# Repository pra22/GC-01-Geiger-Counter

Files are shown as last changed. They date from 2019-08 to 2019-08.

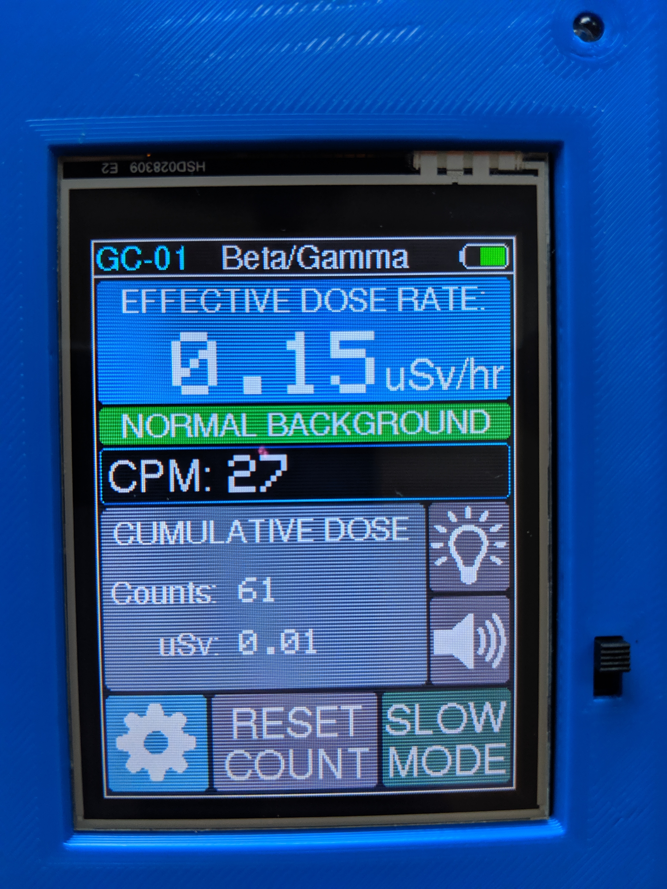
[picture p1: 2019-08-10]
UI Homepage.jpg

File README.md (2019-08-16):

# GC-01-Geiger-Counter
Code and schematics for the GC-01 Geiger counter  

The main program is in src/main.cpp  
Gerbers.zip is the zip file that contains the gerber files for PCB manufacturing. The .zip can be directly uploaded to a PCB manufacturer
like JLCPCB.   
Please refer to the instructable in this link for more details about the porject: https://www.instructables.com/id/DIY-Geiger-Counter-With-an-ESP8266-and-a-Touchscre/

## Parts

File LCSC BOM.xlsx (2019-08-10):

LCSC Part Number | Manufacture Part Number | Manufacturer | Customer NO. | Package | Description | RoHS | Order Qty. | Min\Mult Order Qty. | Unit Price | Order Price
C96061 | PS1720P02 | TDK |  | Plugin | Buzzers Piezo NO 2000Hz 3V Φ17mm Plugin RoHS | Yes | 1 | 1\1 | $0.1697 | $0.17
C99758 | 333-2SURD/S530-A3-L | Everlight Elec |  | Through Hole | Light Emitting Diodes (LED) Red 624nm 200mcd@20mA Top View Through Hole RoHS | Yes | 10 | 10\10 | $0.0355 | $0.36
C118538 | 2N3904 | Semtech |  | TO-92(TO-92-3) | Transistors (NPN/PNP) NPN 200mA 40V TO-92(TO-92-3) RoHS | Yes | 50 | 50\50 | $0.0111 | $0.56
C119313 | - | Chian Chia Elec |  | Axial | Metal Film Resistor (TH) 330Ohms ±1% 1/4W Axial RoHS | Yes | 50 | 50\50 | $0.0053 | $0.27
C119354 | - | Chian Chia Elec |  | Axial | Metal Film Resistor (TH) 22KOhms ±1% 1/4W Axial RoHS | Yes | 50 | 50\50 | $0.0052 | $0.26
C136528 | - | Chian Chia Elec |  | Axial | Metal Film Resistor (TH) 6.2MOhms ±1% 1/4W Axial RoHS | Yes | 50 | 50\50 | $0.0095 | $0.48
C136529 | - | Chian Chia Elec |  | Axial | Metal Film Resistor (TH) 10MOhms ±1% 1/4W Axial RoHS | Yes | 50 | 50\50 | $0.0092 | $0.46
C136718 | SS-12F44-G5 | Korean Hroparts Elec |  | Plugin | Toggle Switches Plugin RoHS | Yes | 5 | 5\5 | $0.0766 | $0.39
C176514 | MFR-25JT-52-3M | YAGEO |  | Axial | Metal Film Resistor (TH) 3MOhms ±5% 1/4W Axial RoHS | Yes | 20 | 20\20 | $0.0168 | $0.34
C182321 | LS-601 | Shenzhen lanson Elec |  | 6.35*32 | Fuse Holders 6.35*32 RoHS | Yes | 10 | 10\10 | $0.0364 | $0.37
C330752 | TJ-L3FYTGHTFCSFLC2R-A5 | TOGIALED |  | Through Hole | Light Emitting Diodes (LED) Red 620~630nm 200~500mcd@20mA Through Hole RoHS | Yes | 20 | 20\20 | $0.0197 | $0.4
C366787 | L06B1B221KQ0T0S0N0 | Songtian Elec |  | Through Hole,P=5.0mm | Ceramic Disc Capacitors 220pF ±10% 500V Through Hole,P=5.0mm RoHS | Yes | 50 | 50\50 | $0.0145 | $0.73
C385438 | RN1/2WS1.8MΩFT/BA1 | TyoHM |  | Axial,2.4x6.5mm | Metal Film Resistor (TH) 1.8MOhms ±1% 1/2W Axial,2.4x6.5mm RoHS | Yes | 50 | 50\50 | $0.0093 | $0.47

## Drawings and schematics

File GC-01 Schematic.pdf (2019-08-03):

## VCC

## VCC

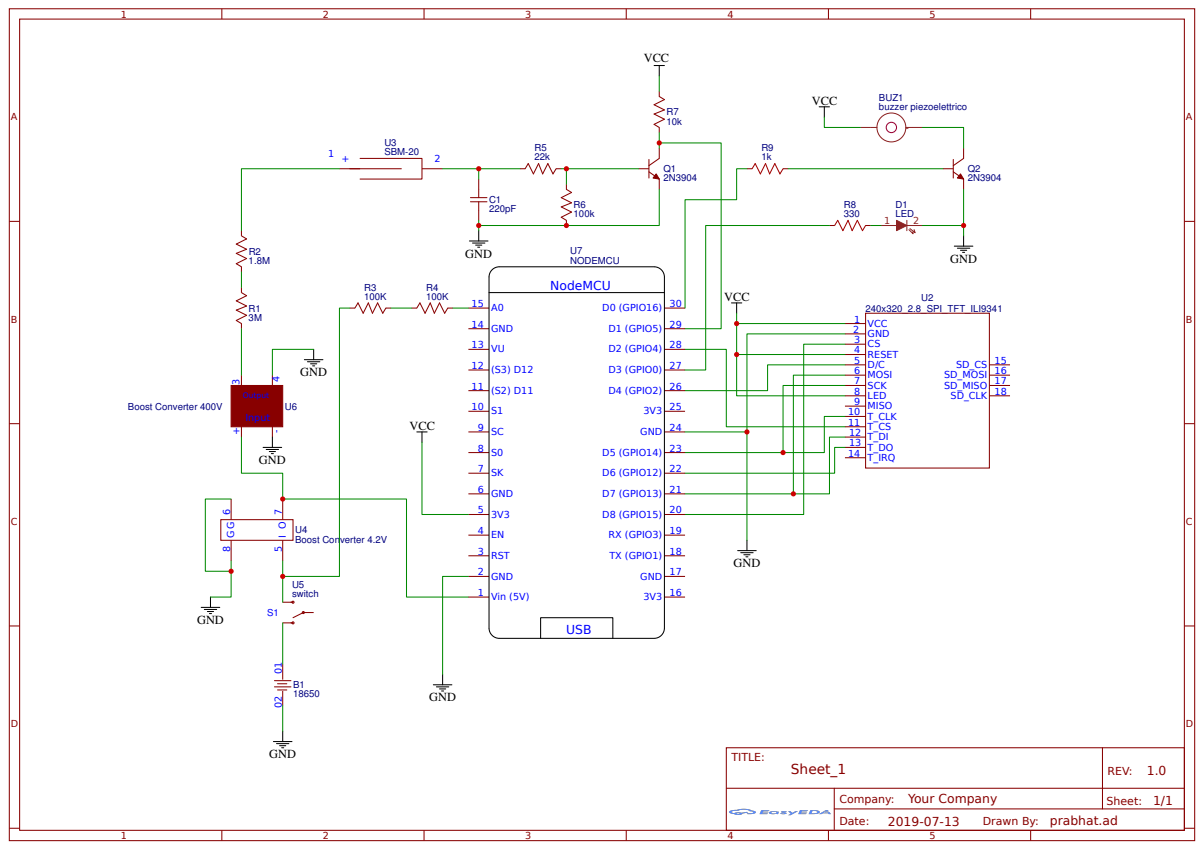
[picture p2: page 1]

Drawn By: prabhat.ad

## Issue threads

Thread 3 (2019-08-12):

BOM Does Not Match Schematic

tonyc770, 2019-08-12:
I noticed that the BOM parts don't all match the schematic. Can you verify?

Thanks!

pra22, 2019-08-12:
Oh that's right I forgot about that. I have edited the Instructables post to include a list of what's needed.

Closed 2019-08-12.

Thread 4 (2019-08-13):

BOM and Schematic Differ

tonyc770, 2019-08-13:
In the BOM it lists a 10M, and 6.2M resistors, but they are not shown in the schematic.
The schematic shows 3, 100K and a 1K resistors, but not in BOM.

pra22, 2019-08-13:
The 10M and 6.2M resistors are for testing, and are not needed for the project. The new list shown in the Instructables is correct.

Closed 2019-08-24.

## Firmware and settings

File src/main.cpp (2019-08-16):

/*  SBM-20 based Geiger Counter
    Author: Prabhat    Email: pra22@pitt.edu
    Sketch for ESP8266 that counts clicks from the Geiger tube, calculates the counts per minute, and displays information 
    on a TFT touchscreen.
    Attribution-NonCommercial-ShareAlike 4.0 International (CC BY-NC-SA 4.0)
*/
#include <Arduino.h>
#include <ESP8266WiFi.h>
#include <EEPROM.h>
#include "SPI.h"
#include "Adafruit_GFX.h"
#include <Fonts/FreeSans9pt7b.h>
#include <Fonts/FreeSans12pt7b.h>
#include "Adafruit_ILI9341.h"
#include <XPT2046_Touchscreen.h>

#define CS_PIN D2
XPT2046_Touchscreen ts(CS_PIN);

#define TS_MINX 250
#define TS_MINY 200 // calibration points for touchscreen
#define TS_MAXX 3800
#define TS_MAXY 3750

#define TFT_DC D4
#define TFT_CS D8

#define BLACK 0x0000
#define BLUE 0x001F
#define RED 0xF800
#define GREEN 0x07E0
#define CYAN 0x07FF
#define MAGENTA 0xF81F
#define YELLOW 0xFFE0
#define WHITE 0xFFFF
#define DOSEBACKGROUND 0x0455

Adafruit_ILI9341 tft = Adafruit_ILI9341(TFT_CS, TFT_DC);

const int interruptPin = 5;

long count[61];
long fastCount[4]; // arrays to store running counts
int i = 0;         // array elements
int j = 0;

int page = 0;

long currentMillis;
long previousMillis;
unsigned long currentMicros;
unsigned long previousMicros;

long averageCount;
unsigned long currentCount;  // incremented by interrupt
unsigned long previousCount; // to activate buzzer and LED
unsigned long cumulativeCount;
float doseRate;
float totalDose;
char dose[5];
float doseAdjusted;

int doseLevel;               // determines home screen warning signs
int previousDoseLevel;

bool ledSwitch = 1;
bool buzzerSwitch = 1;
bool wasTouched;
bool integrationMode = 0; // 0 = slow, 1 = fast

bool doseUnits = 0; // 0 = Sievert, 1 = Rem
int alarmThreshold = 5;
int conversionFactor = 175;

int x, y; // touch points

int batteryInput;
int batteryPercent;
int batteryMapped = 212;       // pixel location of battery icon

const int saveUnits = 0;
const int saveAlertThreshold = 1; // Addresses for storing settings data in the EEPROM
const int saveCalibration = 2;

void ICACHE_RAM_ATTR isr();

const unsigned char settingsBitmap[] PROGMEM = {
    0x00, 0x00, 0x00, 0x00, 0x00, 0x00, 0x00, 0x00, 0x00, 0x00, 0x00, 0x00, 0x00, 0x00, 0x00, 0x00,
    0x00, 0x00, 0x00, 0x00, 0x00, 0x00, 0x00, 0x00, 0x00, 0x00, 0x00, 0x00, 0x00, 0x00, 0x00, 0x00,
    0x00, 0x00, 0x00, 0x00, 0x00, 0x00, 0x00, 0x00, 0x00, 0x00, 0x00, 0x00, 0x00, 0x00, 0x00, 0x00,
    0x00, 0x00, 0x00, 0x00, 0x00, 0x00, 0x00, 0x00, 0x00, 0x00, 0x00, 0x1f, 0x80, 0x00, 0x00, 0x00,
    0x00, 0x00, 0x00, 0x3f, 0xc0, 0x00, 0x00, 0x00, 0x00, 0x00, 0x00, 0x3f, 0xc0, 0x00, 0x00, 0x00,
    0x00, 0x00, 0x00, 0x3f, 0xc0, 0x00, 0x00, 0x00, 0x00, 0x00, 0x00, 0x7f, 0xe0, 0x00, 0x00, 0x00,
    0x00, 0x01, 0xc0, 0x7f, 0xe0, 0x38, 0x00, 0x00, 0x00, 0x03, 0xf0, 0x7f, 0xe0, 0xfc, 0x00, 0x00,
    0x00, 0x07, 0xf9, 0xff, 0xf9, 0xfe, 0x00, 0x00, 0x00, 0x0f, 0xff, 0xff, 0xff, 0xff, 0x00, 0x00,
    0x00, 0x0f, 0xff, 0xff, 0xff, 0xff, 0x00, 0x00, 0x00, 0x0f, 0xff, 0xff, 0xff, 0xff, 0x00, 0x00,
    0x00, 0x07, 0xff, 0xff, 0xff, 0xfe, 0x00, 0x00, 0x00, 0x07, 0xff, 0xff, 0xff, 0xfe, 0x00, 0x00,
    0x00, 0x03, 0xff, 0xff, 0xff, 0xfc, 0x00, 0x00, 0x00, 0x01, 0xff, 0xff, 0xff, 0xf8, 0x00, 0x00,
    0x00, 0x01, 0xff, 0xff, 0xff, 0xf8, 0x00, 0x00, 0x00, 0x03, 0xff, 0xf0, 0x7f, 0xfc, 0x00, 0x00,
    0x00, 0x03, 0xff, 0xc0, 0x3f, 0xfc, 0x00, 0x00, 0x00, 0x1f, 0xff, 0x80, 0x1f, 0xff, 0x80, 0x00,
    0x00, 0xff, 0xff, 0x00, 0x0f, 0xff, 0xf0, 0x00, 0x01, 0xff, 0xff, 0x00, 0x07, 0xff, 0xf8, 0x00,
    0x01, 0xff, 0xfe, 0x00, 0x07, 0xff, 0xf8, 0x00, 0x01, 0xff, 0xfe, 0x00, 0x07, 0xff, 0xf8, 0x00,
    0x01, 0xff, 0xfe, 0x00, 0x07, 0xff, 0xf8, 0x00, 0x01, 0xff, 0xfe, 0x00, 0x07, 0xff, 0xf8, 0x00,
    0x01, 0xff, 0xfe, 0x00, 0x07, 0xff, 0xf8, 0x00, 0x00, 0xff, 0xff, 0x00, 0x0f, 0xff, 0xf0, 0x00,
    0x00, 0x1f, 0xff, 0x80, 0x1f, 0xff, 0x80, 0x00, 0x00, 0x03, 0xff, 0xc0, 0x3f, 0xfc, 0x00, 0x00,
    0x00, 0x03, 0xff, 0xe0, 0x7f, 0xfc, 0x00, 0x00, 0x00, 0x01, 0xff, 0xff, 0xff, 0xf8, 0x00, 0x00,
    0x00, 0x01, 0xff, 0xff, 0xff, 0xf8, 0x00, 0x00, 0x00, 0x03, 0xff, 0xff, 0xff, 0xfc, 0x00, 0x00,
    0x00, 0x07, 0xff, 0xff, 0xff, 0xfe, 0x00, 0x00, 0x00, 0x07, 0xff, 0xff, 0xff, 0xfe, 0x00, 0x00,
    0x00, 0x0f, 0xff, 0xff, 0xff, 0xff, 0x00, 0x00, 0x00, 0x0f, 0xff, 0xff, 0xff, 0xff, 0x00, 0x00,
    0x00, 0x0f, 0xff, 0xff, 0xff, 0xff, 0x00, 0x00, 0x00, 0x07, 0xf9, 0xff, 0xf9, 0xfe, 0x00, 0x00,
    0x00, 0x03, 0xf0, 0x7f, 0xe0, 0xfc, 0x00, 0x00, 0x00, 0x01, 0xc0, 0x7f, 0xe0, 0x38, 0x00, 0x00,
    0x00, 0x00, 0x00, 0x7f, 0xe0, 0x00, 0x00, 0x00, 0x00, 0x00, 0x00, 0x3f, 0xc0, 0x00, 0x00, 0x00,
    0x00, 0x00, 0x00, 0x3f, 0xc0, 0x00, 0x00, 0x00, 0x00, 0x00, 0x00, 0x3f, 0xc0, 0x00, 0x00, 0x00,
    0x00, 0x00, 0x00, 0x1f, 0x80, 0x00, 0x00, 0x00, 0x00, 0x00, 0x00, 0x00, 0x00, 0x00, 0x00, 0x00,
    0x00, 0x00, 0x00, 0x00, 0x00, 0x00, 0x00, 0x00, 0x00, 0x00, 0x00, 0x00, 0x00, 0x00, 0x00, 0x00,
    0x00, 0x00, 0x00, 0x00, 0x00, 0x00, 0x00, 0x00, 0x00, 0x00, 0x00, 0x00, 0x00, 0x00, 0x00, 0x00,
    0x00, 0x00, 0x00, 0x00, 0x00, 0x00, 0x00, 0x00, 0x00, 0x00, 0x00, 0x00, 0x00, 0x00, 0x00, 0x00};

const unsigned char buzzerOnBitmap[] PROGMEM = {
    0x00, 0x00, 0x00, 0x00, 0x00, 0x00, 0x00, 0x00, 0x00, 0x00, 0x00, 0x00, 0x00, 0x00, 0x00, 0x00,
    0x00, 0x00, 0x00, 0x00, 0x00, 0x00, 0x00, 0x00, 0x00, 0x00, 0x00, 0x00, 0x00, 0x00, 0x00, 0x00,
    0x00, 0x00, 0x00, 0x00, 0x00, 0x00, 0x00, 0x00, 0x00, 0x00, 0x00, 0x00, 0x03, 0x80, 0x0c, 0x00,
    0x00, 0x00, 0x07, 0x80, 0x0e, 0x00, 0x00, 0x00, 0x0f, 0x80, 0x0f, 0x00, 0x00, 0x00, 0x1f, 0x80,
    0x07, 0x00, 0x00, 0x00, 0x3f, 0x80, 0xc7, 0x80, 0x00, 0x00, 0xff, 0x80, 0xe3, 0x80, 0x00, 0x01,
    0xff, 0x80, 0xf3, 0xc0, 0x00, 0x03, 0xff, 0x80, 0x71, 0xc0, 0x00, 0x07, 0xff, 0x8c, 0x79, 0xc0,
    0x3f, 0xff, 0xff, 0x9e, 0x38, 0xe0, 0x3f, 0xff, 0xff, 0x8e, 0x38, 0xe0, 0x3f, 0xff, 0xff, 0x8e,
    0x3c, 0xe0, 0x3f, 0xff, 0xff, 0x87, 0x1c, 0xe0, 0x3f, 0xff, 0xff, 0x87, 0x1c, 0x60, 0x3f, 0xff,
    0xff, 0x87, 0x1c, 0x70, 0x3f, 0xff, 0xff, 0x87, 0x1c, 0x70, 0x3f, 0xff, 0xff, 0x87, 0x1c, 0x70,
    0x3f, 0xff, 0xff, 0x87, 0x1c, 0x70, 0x3f, 0xff, 0xff, 0x87, 0x1c, 0x70, 0x3f, 0xff, 0xff, 0x87,
    0x1c, 0xe0, 0x3f, 0xff, 0xff, 0x8e, 0x3c, 0xe0, 0x3f, 0xff, 0xff, 0x8e, 0x38, 0xe0, 0x3f, 0xff,
    0xff, 0x9e, 0x38, 0xe0, 0x00, 0x07, 0xff, 0x8c, 0x79, 0xc0, 0x00, 0x03, 0xff, 0x80, 0x71, 0xc0,
    0x00, 0x00, 0xff, 0x80, 0xf1, 0xc0, 0x00, 0x00, 0x7f, 0x80, 0xe3, 0x80, 0x00, 0x00, 0x3f, 0x80,
    0xc7, 0x80, 0x00, 0x00, 0x1f, 0x80, 0x07, 0x00, 0x00, 0x00, 0x0f, 0x80, 0x0f, 0x00, 0x00, 0x00,
    0x07, 0x80, 0x0e, 0x00, 0x00, 0x00, 0x03, 0x80, 0x0c, 0x00, 0x00, 0x00, 0x00, 0x00, 0x00, 0x00,
    0x00, 0x00, 0x00, 0x00, 0x00, 0x00, 0x00, 0x00, 0x00, 0x00, 0x00, 0x00, 0x00, 0x00, 0x00, 0x00,
    0x00, 0x00, 0x00, 0x00, 0x00, 0x00, 0x00, 0x00, 0x00, 0x00, 0x00, 0x00, 0x00, 0x00};

const unsigned char buzzerOffBitmap[] PROGMEM = {
    0x00, 0x00, 0x00, 0x00, 0x00, 0x00, 0x00, 0x00, 0x00, 0x00, 0x00, 0x00, 0x00, 0x00, 0x03, 0x80,
    0x00, 0x00, 0x00, 0x00, 0x0f, 0x80, 0x00, 0x00, 0x00, 0x00, 0x1f, 0x80, 0x00, 0x00, 0x00, 0x00,
    0x3f, 0x80, 0x00, 0x00, 0x00, 0x00, 0x7f, 0x80, 0x00, 0x00, 0x00, 0x00, 0xff, 0x80, 0x00, 0x00,
    0x00, 0x03, 0xff, 0x80, 0x00, 0x00, 0x00, 0x07, 0xff, 0x80, 0x00, 0x00, 0x00, 0x0f, 0xff, 0x80,
    0x00, 0x00, 0x0f, 0xff, 0xff, 0x80, 0x00, 0x00, 0x1f, 0xff, 0xff, 0x80, 0x00, 0x00, 0x3f, 0xff,
    0xff, 0x8f, 0x00, 0x78, 0x7f, 0xff, 0xff, 0x8f, 0x80, 0xf8, 0x7f, 0xff, 0xff, 0x8f, 0xc1, 0xf8,
    0x7f, 0xff, 0xff, 0x87, 0xe3, 0xf0, 0x7f, 0xff, 0xff, 0x83, 0xf7, 0xe0, 0x7f, 0xff, 0xff, 0x81,
    0xff, 0xc0, 0x7f, 0xff, 0xff, 0x80, 0xff, 0x80, 0x7f, 0xff, 0xff, 0x80, 0x7f, 0x00, 0x7f, 0xff,
    0xff, 0x80, 0x7f, 0x00, 0x7f, 0xff, 0xff, 0x80, 0xff, 0x80, 0x7f, 0xff, 0xff, 0x81, 0xff, 0xc0,
    0x7f, 0xff, 0xff, 0x83, 0xf7, 0xe0, 0x7f, 0xff, 0xff, 0x87, 0xe3, 0xf0, 0x7f, 0xff, 0xff, 0x8f,
    0xc1, 0xf0, 0x7f, 0xff, 0xff, 0x8f, 0x80, 0xf8, 0x3f, 0xff, 0xff, 0x8f, 0x00, 0x70, 0x3f, 0xff,
    0xff, 0x84, 0x00, 0x20, 0x1f, 0xff, 0xff, 0x80, 0x00, 0x00, 0x0f, 0xff, 0xff, 0x80, 0x00, 0x00,
    0x00, 0x07, 0xff, 0x80, 0x00, 0x00, 0x00, 0x03, 0xff, 0x80, 0x00, 0x00, 0x00, 0x01, 0xff, 0x80,
    0x00, 0x00, 0x00, 0x00, 0xff, 0x80, 0x00, 0x00, 0x00, 0x00, 0x7f, 0x80, 0x00, 0x00, 0x00, 0x00,
    0x1f, 0x80, 0x00, 0x00, 0x00, 0x00, 0x0f, 0x80, 0x00, 0x00, 0x00, 0x00, 0x07, 0x80, 0x00, 0x00,
    0x00, 0x00, 0x03, 0x80, 0x00, 0x00, 0x00, 0x00, 0x00, 0x00, 0x00, 0x00, 0x00, 0x00, 0x00, 0x00,
    0x00, 0x00, 0x00, 0x00, 0x00, 0x00, 0x00, 0x00, 0x00, 0x00, 0x00, 0x00, 0x00, 0x00};

const unsigned char ledOnBitmap[] PROGMEM = {
    0x00, 0x00, 0x02, 0x00, 0x00, 0x00, 0x00, 0x00, 0x07, 0x00, 0x00, 0x00, 0x00, 0x00, 0x07, 0x00,
    0x00, 0x00, 0x00, 0x18, 0x07, 0x00, 0xc0, 0x00, 0x00, 0x1c, 0x07, 0x01, 0xc0, 0x00, 0x00, 0x1e,
    0x07, 0x03, 0xc0, 0x00, 0x00, 0x0e, 0x07, 0x03, 0x80, 0x00, 0x00, 0x0f, 0x00, 0x07, 0x80, 0x00,
    0x00, 0x07, 0x00, 0x07, 0x00, 0x00, 0x00, 0x00, 0x00, 0x00, 0x00, 0x00, 0x00, 0x00, 0x00, 0x00,
    0x00, 0x00, 0x1e, 0x00, 0x1f, 0xc0, 0x03, 0xc0, 0x0f, 0x80, 0x7f, 0xf0, 0x0f, 0x80, 0x07, 0xc1,
    0xff, 0xfc, 0x1f, 0x00, 0x03, 0xc3, 0xe0, 0x3e, 0x1e, 0x00, 0x00, 0x07, 0xc0, 0x0f, 0x00, 0x00,
    0x00, 0x07, 0x00, 0x07, 0x00, 0x00, 0x00, 0x0f, 0x00, 0x07, 0x80, 0x00, 0x00, 0x0e, 0x00, 0x03,
    0x80, 0x00, 0x00, 0x0e, 0x00, 0x03, 0x80, 0x00, 0x00, 0x1c, 0x00, 0x01, 0xc0, 0x00, 0x7f, 0x1c,
    0x00, 0x01, 0xc3, 0xf0, 0x7f, 0x1c, 0x00, 0x01, 0xc7, 0xf0, 0x3c, 0x0e, 0x00, 0x03, 0x81, 0xe0,
    0x00, 0x0e, 0x00, 0x03, 0x80, 0x00, 0x00, 0x0e, 0x00, 0x03, 0x80, 0x00, 0x00, 0x0f, 0x00, 0x07,
    0x80, 0x00, 0x00, 0x07, 0x00, 0x07, 0x00, 0x00, 0x00, 0x07, 0x80, 0x0f, 0x00, 0x00, 0x01, 0xc3,
    0xc0, 0x1e, 0x1c, 0x00, 0x07, 0xc1, 0xc0, 0x1c, 0x1f, 0x00, 0x0f, 0x81, 0xe0, 0x3c, 0x0f, 0x80,
    0x1e, 0x00, 0xe0, 0x38, 0x03, 0xc0, 0x0c, 0x00, 0xe0, 0x38, 0x01, 0x80, 0x00, 0x00, 0xf0, 0x78,
    0x00, 0x00, 0x00, 0x00, 0x7f, 0xf0, 0x00, 0x00, 0x00, 0x00, 0x7f, 0xf0, 0x00, 0x00, 0x00, 0x00,
    0x3f, 0xe0, 0x00, 0x00, 0x00, 0x00, 0x3f, 0xe0, 0x00, 0x00, 0x00, 0x00, 0x3f, 0xe0, 0x00, 0x00,
    0x00, 0x00, 0x3f, 0xe0, 0x00, 0x00, 0x00, 0x00, 0x3f, 0xe0, 0x00, 0x00, 0x00, 0x00, 0x3f, 0xe0,
    0x00, 0x00, 0x00, 0x00, 0x1f, 0xc0, 0x00, 0x00, 0x00, 0x00, 0x07, 0x00, 0x00, 0x00};

const unsigned char ledOffBitmap[] PROGMEM = {
    0x00, 0x00, 0x00, 0x00, 0x00, 0x00, 0x00, 0x00, 0x00, 0x00, 0x00, 0x00, 0x00, 0x00, 0x00, 0x00,
    0x00, 0x00, 0x00, 0x00, 0x00, 0x00, 0x00, 0x00, 0x00, 0x00, 0x00, 0x00, 0x00, 0x00, 0x00, 0x00,
    0x00, 0x00, 0x00, 0x00, 0x00, 0x00, 0x00, 0x00, 0x00, 0x00, 0x00, 0x00, 0x00, 0x00, 0x00, 0x00,
    0x00, 0x00, 0x00, 0x00, 0x00, 0x00, 0x00, 0x00, 0x00, 0x00, 0x00, 0x00, 0x00, 0x00, 0x00, 0x00,
    0x00, 0x00, 0x00, 0x00, 0x1f, 0xc0, 0x00, 0x00, 0x00, 0x00, 0x7f, 0xf0, 0x00, 0x00, 0x00, 0x01,
    0xff, 0xfc, 0x00, 0x00, 0x00, 0x03, 0xe0, 0x3e, 0x00, 0x00, 0x00, 0x07, 0xc0, 0x0f, 0x00, 0x00,
    0x00, 0x07, 0x00, 0x07, 0x00, 0x00, 0x00, 0x0f, 0x00, 0x07, 0x80, 0x00, 0x00, 0x0e, 0x00, 0x03,
    0x80, 0x00, 0x00, 0x0e, 0x00, 0x03, 0x80, 0x00, 0x00, 0x1c, 0x00, 0x01, 0xc0, 0x00, 0x00, 0x1c,
    0x00, 0x01, 0xc0, 0x00, 0x00, 0x1c, 0x00, 0x01, 0xc0, 0x00, 0x00, 0x0e, 0x00, 0x03, 0x80, 0x00,
    0x00, 0x0e, 0x00, 0x03, 0x80, 0x00, 0x00, 0x0e, 0x00, 0x03, 0x80, 0x00, 0x00, 0x0f, 0x00, 0x07,
    0x80, 0x00, 0x00, 0x07, 0x00, 0x07, 0x00, 0x00, 0x00, 0x07, 0x80, 0x0f, 0x00, 0x00, 0x00, 0x03,
    0xc0, 0x1e, 0x00, 0x00, 0x00, 0x01, 0xc0, 0x1c, 0x00, 0x00, 0x00, 0x01, 0xe0, 0x3c, 0x00, 0x00,
    0x00, 0x00, 0xe0, 0x38, 0x00, 0x00, 0x00, 0x00, 0xe0, 0x38, 0x00, 0x00, 0x00, 0x00, 0xf0, 0x78,
    0x00, 0x00, 0x00, 0x00, 0x7f, 0xf0, 0x00, 0x00, 0x00, 0x00, 0x7f, 0xf0, 0x00, 0x00, 0x00, 0x00,
    0x3f, 0xe0, 0x00, 0x00, 0x00, 0x00, 0x3f, 0xe0, 0x00, 0x00, 0x00, 0x00, 0x3f, 0xe0, 0x00, 0x00,
    0x00, 0x00, 0x3f, 0xe0, 0x00, 0x00, 0x00, 0x00, 0x3f, 0xe0, 0x00, 0x00, 0x00, 0x00, 0x3f, 0xe0,
    0x00, 0x00, 0x00, 0x00, 0x1f, 0xc0, 0x00, 0x00, 0x00, 0x00, 0x07, 0x00, 0x00, 0x00};
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
void loop()
{
  if (page == 0) // homepage
  {
    currentMillis = millis();
    if (currentMillis - previousMillis >= 1000)
    {
      previousMillis = currentMillis;

      batteryInput = analogRead(A0);
      batteryInput = constrain(batteryInput, 670, 870);
      batteryPercent = map(batteryInput, 670, 870, 0, 100);
      batteryMapped = map(batteryPercent, 100, 0, 212, 233);

      tft.fillRect(212, 6, 22, 10, ILI9341_BLACK);
      tft.fillRect(batteryMapped, 6, (234 - batteryMapped), 10, ILI9341_GREEN); // draws battery icon every second

      count[i] = currentCount;
      i++;
      fastCount[j] = currentCount; // keep concurrent arrays of counts. Use only one depending on user choice
      j++;

      if (i == 61)
      {
        i = 0;
      }

      if (j == 4)
      {
        j = 0;
      }

      if (integrationMode == 1)
      {
        averageCount = (currentCount - fastCount[j]) * 20;
      }

      else
      {
        averageCount = currentCount - count[i]; // count[i] stores the value from 60 seconds ago
      }

      averageCount = ((averageCount) / (1 - 0.00000333 * float(averageCount))); // accounts for dead time of the geiger tube. relevant at high count rates

      if (doseUnits == 0)
      {
        doseRate = averageCount / float(conversionFactor);
        totalDose = cumulativeCount / (60 * float(conversionFactor));
        doseAdjusted = doseRate;
      }
      else if (doseUnits == 1)
      {
        doseRate = averageCount / float(conversionFactor * 10.0);
        totalDose = cumulativeCount / (60 * float(conversionFactor * 10.0)); // 1 mRem == 10 uSv
        doseAdjusted = doseRate * 10.0;
      }

      if (doseAdjusted < 1)
        doseLevel = 0; // determines alert level displayed on homescreen
      else if (doseAdjusted < alarmThreshold)
        doseLevel = 1;
      else
        doseLevel = 2;

      if (doseRate < 10)
      {
        dtostrf(doseRate, 4, 2, dose); // display two digits after the decimal point if value is less than 10
      }
      else if ((doseRate >= 10) && (doseRate < 100))
      {
        dtostrf(doseRate, 4, 1, dose); // display one digit after decimal point when dose is greater than 10
      }
      else if ((doseRate >= 100))
      {
        dtostrf(doseRate, 4, 0, dose); // whole numbers only when dose is higher than 100
      }
      
      tft.setFont();
      tft.setCursor(44, 52);
      tft.setTextSize(5);
      tft.setTextColor(ILI9341_WHITE, DOSEBACKGROUND);
      tft.println(dose); // display effective dose rate
      tft.setTextSize(1);

      tft.setFont();
      tft.setCursor(75, 122);
      tft.setTextColor(ILI9341_WHITE, ILI9341_BLACK);
      tft.setTextSize(3);
      tft.println(averageCount); // Display CPM

      if (averageCount < 10)
      {
        tft.fillRect(92, 120, 100, 25, ILI9341_BLACK); // erase numbers that may have been left from previous high readings
      }
      else if (averageCount < 100)
      {
        tft.fillRect(109, 120, 90, 25, ILI9341_BLACK);
      }
      else if (averageCount < 1000)
      {
        tft.fillRect(126, 120, 75, 25, ILI9341_BLACK);
      }
      else if (averageCount < 10000)
      {
        tft.fillRect(143, 120, 60, 25, ILI9341_BLACK);
      }
      else if (averageCount < 100000)
      {
        tft.fillRect(162, 120, 45, 25, ILI9341_BLACK);
      }
      tft.setCursor(80, 192);
      tft.setTextSize(2);
      tft.setTextColor(ILI9341_WHITE, 0x630C);
      tft.println(cumulativeCount); // display total counts since reset

      tft.setCursor(80, 222);
      tft.println(totalDose); // display cumulative dose

      if (doseLevel != previousDoseLevel) // only update alert level if it changed. This prevents flicker
      {
        if (doseLevel == 0)
        {
          tft.drawRect(0, 0, tft.width(), tft.height(), ILI9341_WHITE);
          tft.fillRoundRect(3, 94, 234, 21, 3, 0x2DC6);
          tft.setCursor(15, 104);
          tft.setFont(&FreeSans9pt7b);
          tft.setTextColor(ILI9341_WHITE);
          tft.setTextSize(1);
          tft.println("NORMAL BACKGROUND");

          previousDoseLevel = doseLevel;
        }
        else if (doseLevel == 1)
        {
          tft.drawRect(0, 0, tft.width(), tft.height(), ILI9341_WHITE);
          tft.fillRoundRect(3, 94, 234, 21, 3, 0xCE40);
          tft.setCursor(29, 104);
          tft.setFont(&FreeSans9pt7b);
          tft.setTextColor(ILI9341_WHITE);
          tft.setTextSize(1);
          tft.println("ELEVATED ACTIVITY");

          previousDoseLevel = doseLevel;
        }
        else if (doseLevel == 2)
        {
          tft.drawRect(0, 0, tft.width(), tft.height(), ILI9341_RED);
          tft.fillRoundRect(3, 94, 234, 21, 3, 0xB8A2);
          tft.setCursor(17, 104);
          tft.setFont(&FreeSans9pt7b);
          tft.setTextColor(ILI9341_WHITE);
          tft.setTextSize(1);
          tft.println("HIGH RADIATION LEVEL");

          previousDoseLevel = doseLevel;
        }
      }
    } // end of millis()-controlled block that runs once every second. The rest of the code on page 0 runs every loop
    if (currentCount > previousCount)
    {
      if (ledSwitch)
        digitalWrite(D3, HIGH); // trigger buzzer and led if they are activated
      if (buzzerSwitch)
        digitalWrite(D0, HIGH);
      previousCount = currentCount;
      previousMicros = micros();
    }
    currentMicros = micros();
    if (currentMicros - previousMicros >= 200)
    {
      digitalWrite(D3, LOW);
      digitalWrite(D0, LOW);
      previousMicros = currentMicros;
    }

    if (!ts.touched())
      wasTouched = 0;
    if (ts.touched() && !wasTouched) // A way of "debouncing" the touchscreen. Prevents multiple inputs from single touch
    {
      wasTouched = 1;
      TS_Point p = ts.getPoint();
      x = map(p.x, TS_MINX, TS_MAXX, 240, 0); // get touch point and map to screen pixels
      y = map(p.y, TS_MINY, TS_MAXY, 320, 0);

      if ((x > 162 && x < 238) && (y > 259 && y < 318))
      {
        integrationMode = !integrationMode;
        currentCount = 0;
        previousCount = 0;
        for (int a = 0; a < 60; a++) // reset counts when integretation speed is changed
        {
          count[a] = 0;
        }
        for (int b = 0; b < 4; b++)
        {
          fastCount[b] = 0;
        }
        if (integrationMode == 0) // change button based on touch and previous state
        {
          tft.fillRoundRect(162, 259, 75, 57, 3, 0x2A86);
          tft.setFont(&FreeSans12pt7b);
          tft.setTextSize(1);
          tft.setCursor(163, 284);
          tft.println("SLOW");
          tft.setCursor(164, 309);
          tft.println("MODE");
        }
        else
        {
          tft.fillRoundRect(162, 259, 75, 57, 3, 0x2A86);
          tft.setFont(&FreeSans12pt7b);
          tft.setTextSize(1);
          tft.setCursor(169, 284);
          tft.println("FAST");
          tft.setCursor(164, 309);
          tft.println("MODE");
        }
      }
      else if ((x > 64 && x < 159) && (y > 259 && y < 318)) // reset count
      {
        currentCount = 0;
        previousCount = 0;
        for (int a = 0; a < 60; a++)
        {
          count[a] = 0;
        }
        for (int b = 0; b < 4; b++)
        {
          fastCount[b] = 0;
        }
      }
      else if ((x > 190 && x < 238) && (y > 151 && y < 202)) // toggle LED
      {
        ledSwitch = !ledSwitch;
        if (ledSwitch)
        {
          tft.fillRoundRect(190, 151, 46, 51, 3, 0x6269);
          tft.drawBitmap(190, 153, ledOnBitmap, 45, 45, ILI9341_WHITE);
        }
        else
        {
          tft.fillRoundRect(190, 151, 46, 51, 3, 0x6269);
          tft.drawBitmap(190, 153, ledOffBitmap, 45, 45, ILI9341_WHITE);
        }
      }
      else if ((x > 190 && x < 238) && (y > 205 && y < 256)) // toggle buzzer
      {
        buzzerSwitch = !buzzerSwitch;
        if (buzzerSwitch)
        {
          tft.fillRoundRect(190, 205, 46, 51, 3, 0x6269);
          tft.drawBitmap(190, 208, buzzerOnBitmap, 45, 45, ILI9341_WHITE);
        }
        else
        {
          tft.fillRoundRect(190, 205, 46, 51, 3, 0x6269);
          tft.drawBitmap(190, 208, buzzerOffBitmap, 45, 45, ILI9341_WHITE);
        }
      }
      else if ((x > 3 && x < 61) && (y > 259 && y < 316)) // settings button pressed
      {
        page = 1;
        drawSettingsPage();
      }
    }
  }
  else if (page == 1) // settings page. all display elements are drawn when drawSettingsPage() is called
  {
    if (!ts.touched())
      wasTouched = 0;
    if (ts.touched() && !wasTouched)
    {
      wasTouched = 1;
      TS_Point p = ts.getPoint();
      x = map(p.x, TS_MINX, TS_MAXX, 240, 0);
      y = map(p.y, TS_MINY, TS_MAXY, 320, 0);
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

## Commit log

2019-08-07 Added EEPROM saving so settings can be retrieved when device is reset
    [main.cpp]
2019-08-08 Fixed some comment typos
    [main.cpp]
2019-08-10 Gerber files for PCB
    [Gerber_BoardOutline.GKO, Gerber_BottomLayer.GBL, Gerber_BottomPasteMaskLayer.GBP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]
2019-08-10 Added BOM of parts
    [LCSC BOM.xlsx]
2019-08-10 Moved code for dose display up - to prevent rare bug where dose reading partially blocks the unit characters
    [main.cpp]
2019-08-12 Added zip folder of gerbers
    [Gerber_BoardOutline.GKO, Gerber_BottomLayer.GBL, Gerber_BottomPasteMaskLayer.GBP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]
2019-08-16 Fixed bug where large numbers would appear on the screen.
    [main.cpp]
2019-08-16 Disabled Wifi to save power
